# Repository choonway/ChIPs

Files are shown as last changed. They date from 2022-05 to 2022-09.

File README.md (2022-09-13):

# ChIPs - Polycube/Voxel Construction Set

## [GPGT] No more SNOT. You will only need 4 types of bricks

| polycube/voxel | ChIPs |
| --- | --- |
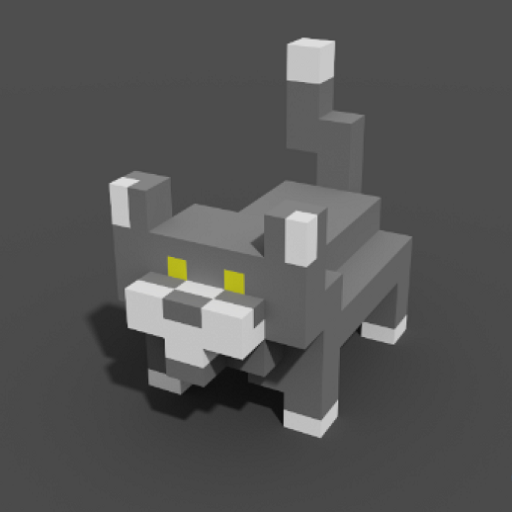
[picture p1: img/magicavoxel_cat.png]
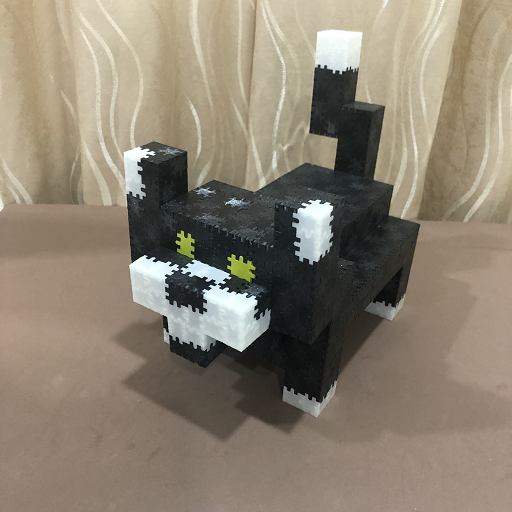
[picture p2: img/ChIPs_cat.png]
|  |  |

## tl;dr
Have you wanted to use a construction set to build a model, but don't want to deal with complicated techniques to remove studs / build sideways? Not Square? Too many different types of bricks? Something you can freely 3D print cheaply? etc. Look no further, this is the construction set for you!

## Introduction
ChIPs (Choonway's Interlocking Panels) is an open source (CC-BY 4.0) construction set system that uses interlocking finger joints between panels orientated at 0 degrees or 90 degrees with respect to each other. The resulting object has smooth surfaces on all faces, sharp edges and results in a close physical manifestation of polycube puzzles / voxel art.

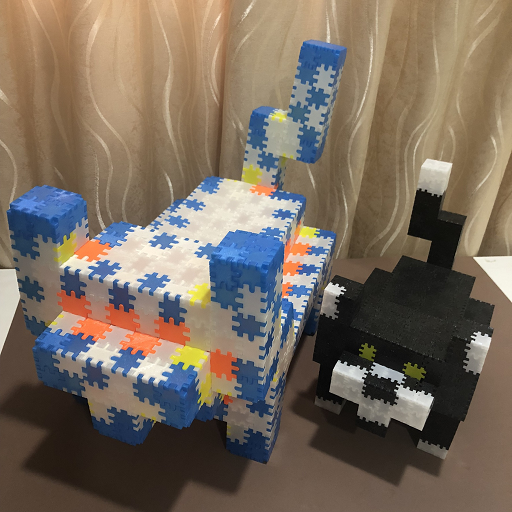
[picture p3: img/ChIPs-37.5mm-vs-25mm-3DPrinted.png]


On the left is the 37.5mm cube variant with panels colored by type. On the right is the featured cat model using 25mm cube variant with sharp corners. The dimension of the cube variant refers to the length of the side of the unit cube.

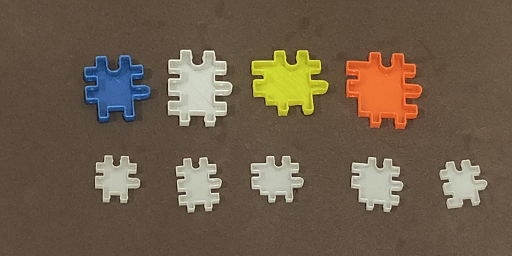
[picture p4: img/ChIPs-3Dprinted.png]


Only 4 unique panels (Blue, White, Yellow and Orange) are required for building any model. The 5th panel is optional for sharp corners. Note the sharpness of the ears between the 2 models.

## Guided Build Tutorial

At first glance it might seem confusing which panels to join together to make the object, but not to worry, there is an easy way to figure it with the use of [Ephtracy's MagicaVoxel](https://ephtracy.github.io/).

I call this the 'bubblebath' technique. vox files available [here](vox/cat_tut.vox)

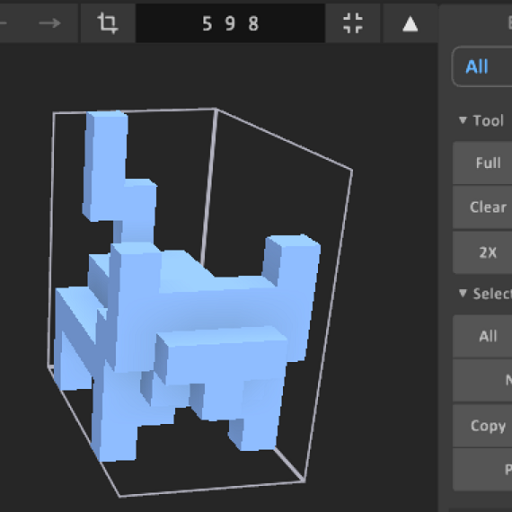
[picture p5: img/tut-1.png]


Here we start off with a cat voxel shape, with one voxel per unit cube.
Click on 'Fit Model Size' and take note of the bounding box size X = (5, 9, 8) of the original model

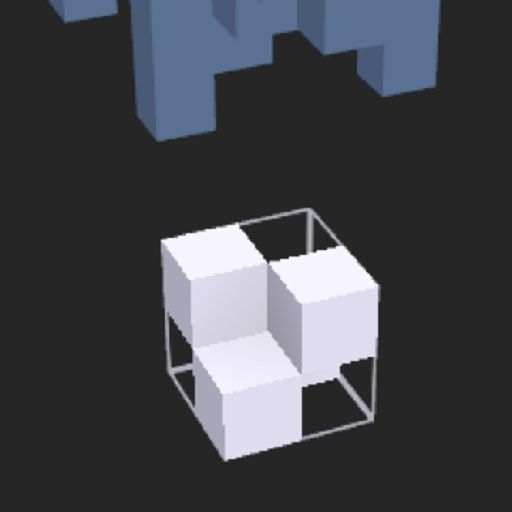
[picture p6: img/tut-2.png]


Create the unit bubble (3D checkerboard on a 2x2x2 volume)

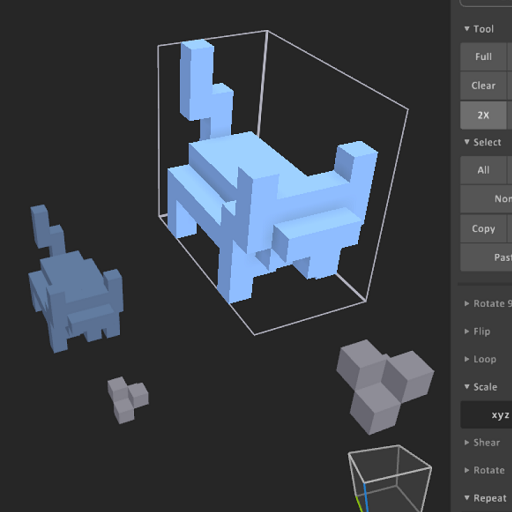
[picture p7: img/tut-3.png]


Double the size of the bubble and cat

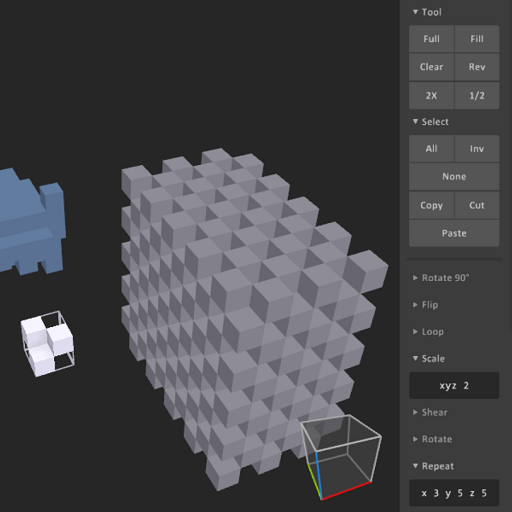
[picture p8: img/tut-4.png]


Expand the bubble using the formula below

floor(X/2)+1 = (3, 5, 5)

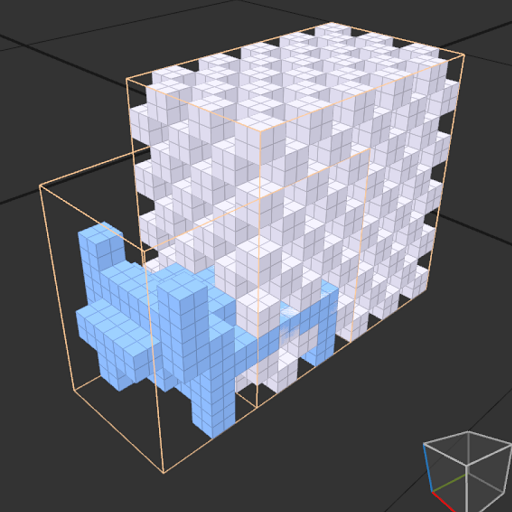
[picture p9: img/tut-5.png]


Grid lines shown for clarity.
Move the cat into the bubble, align with right face,

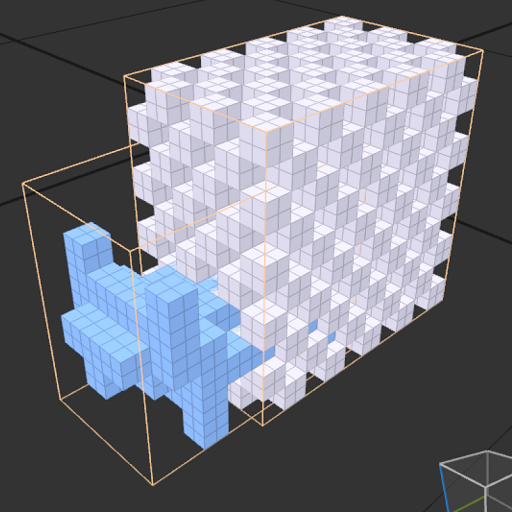
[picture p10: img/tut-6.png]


and take one step into the bubble.

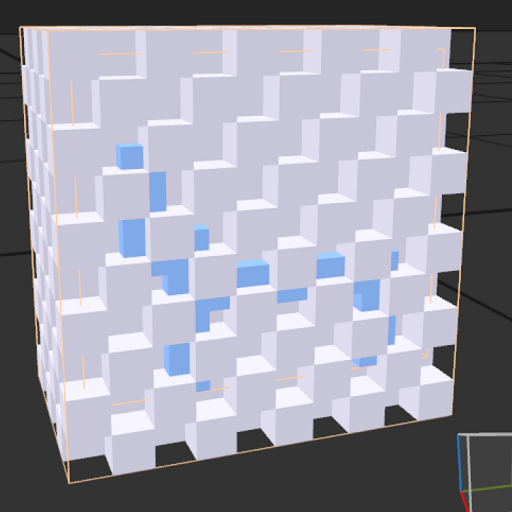
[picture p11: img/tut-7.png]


Repeat for front and top faces
In effect we are intermeshing the bubbles a half cube step with the cat model.

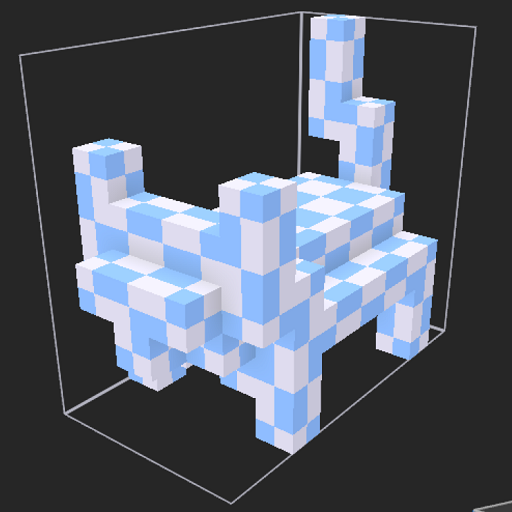
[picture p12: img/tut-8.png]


In the World View,
Click on the bubbles, then the boolean 'operand', the bubbles should disappear.
Click on the cat model, then click on the boolean 'replace', a pattern should appear on the cat.

Examine the patterns on the frazzled cat. They should match one of the 12 fragments. vox files available [here](vox/cat_frag.vox)

| fragment | ChIPs build youtube video | example locations on cat |
| --- | --- | --- |
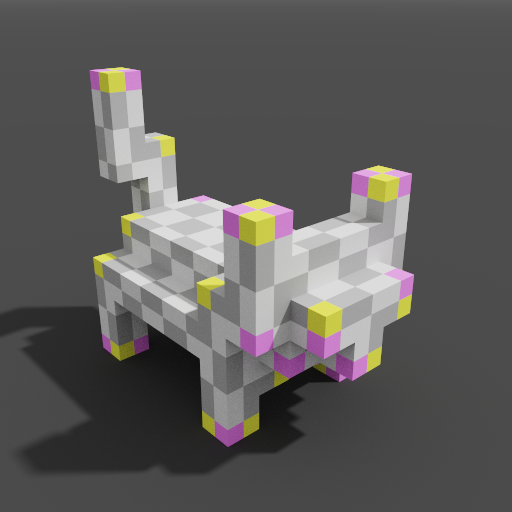
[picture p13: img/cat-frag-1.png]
| 1 | [0:04](https://www.youtube.com/watch?v=te_LA7-NAmI&t=4s) |  |
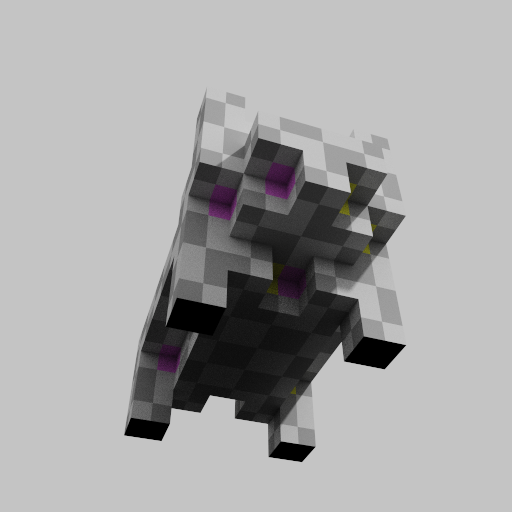
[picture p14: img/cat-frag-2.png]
| 2 | [0:22](https://www.youtube.com/watch?v=te_LA7-NAmI&t=22s) |  |
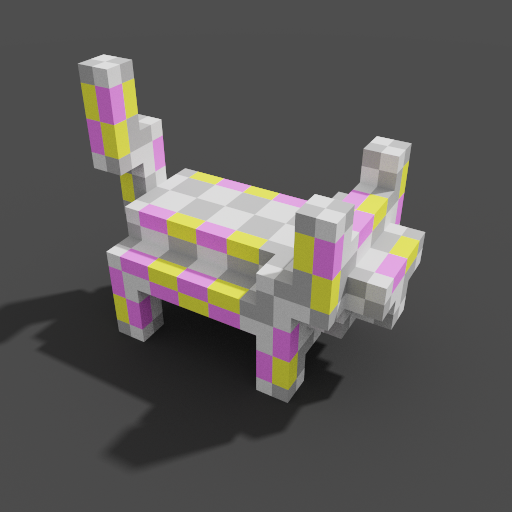
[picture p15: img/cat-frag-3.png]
| 3 | [0:44](https://www.youtube.com/watch?v=te_LA7-NAmI&t=44s) |  |
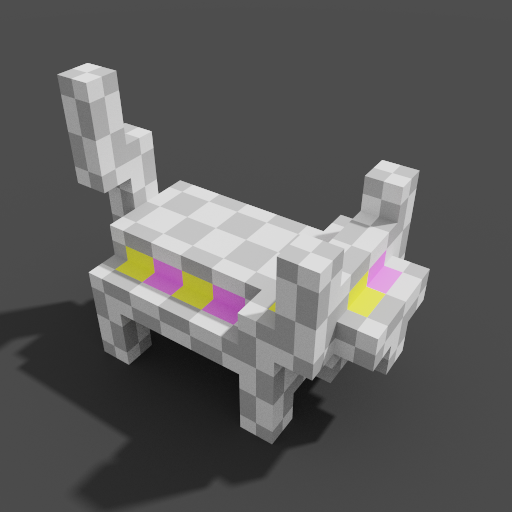
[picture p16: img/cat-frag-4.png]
| 4 | [1:14](https://www.youtube.com/watch?v=te_LA7-NAmI&t=74s) |  |
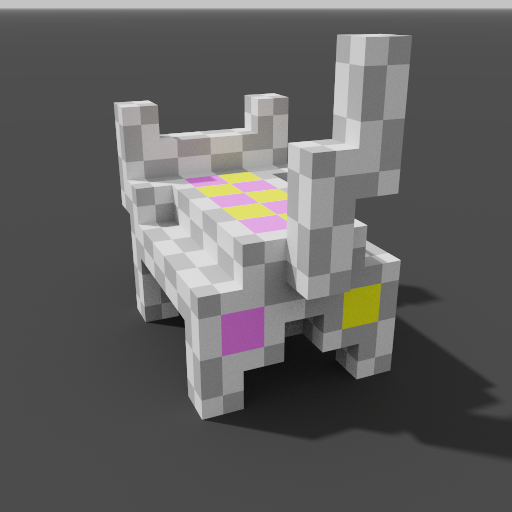
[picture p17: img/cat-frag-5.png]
| 5 | [1:54](https://www.youtube.com/watch?v=te_LA7-NAmI&t=114s) |  |
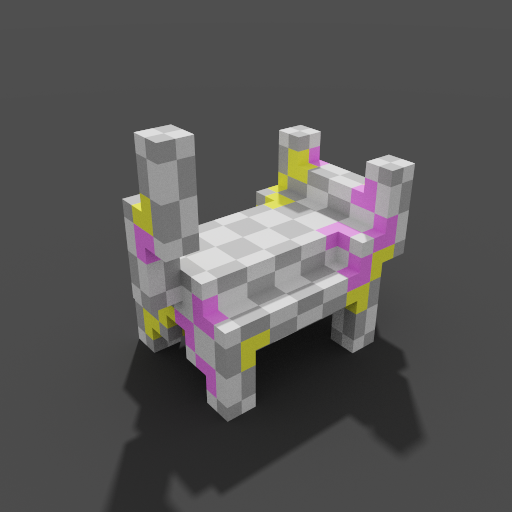
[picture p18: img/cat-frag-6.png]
| 6 | [2:25](https://www.youtube.com/watch?v=te_LA7-NAmI&t=145s) |  |
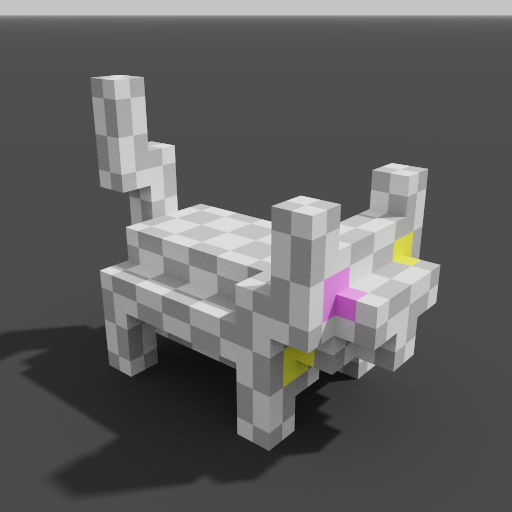
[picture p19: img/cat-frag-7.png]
| 7 | [2:56](https://www.youtube.com/watch?v=te_LA7-NAmI&t=176s) |  |
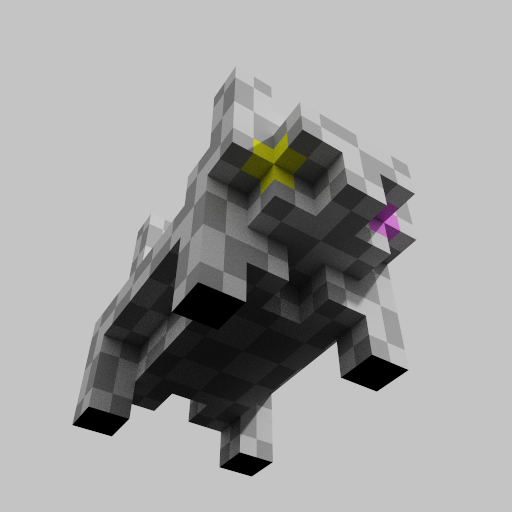
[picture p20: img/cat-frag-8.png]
| 8 | [3:31](https://www.youtube.com/watch?v=te_LA7-NAmI&t=211s) |  |
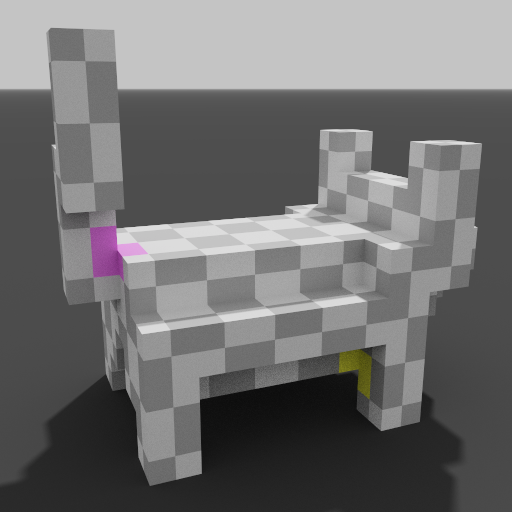
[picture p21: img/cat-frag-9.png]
| 9 | [4:29](https://www.youtube.com/watch?v=te_LA7-NAmI&t=269s) |  |
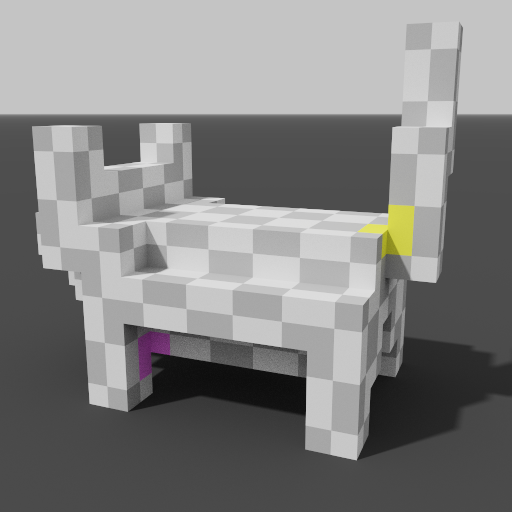
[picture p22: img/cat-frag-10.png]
| 10 | [5:14](https://www.youtube.com/watch?v=te_LA7-NAmI&t=314s) |  |
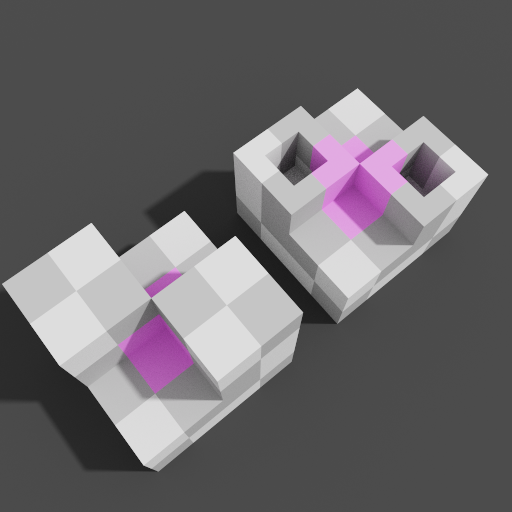
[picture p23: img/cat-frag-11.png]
| 11 | [6:00](https://www.youtube.com/watch?v=te_LA7-NAmI&t=360s) |  |
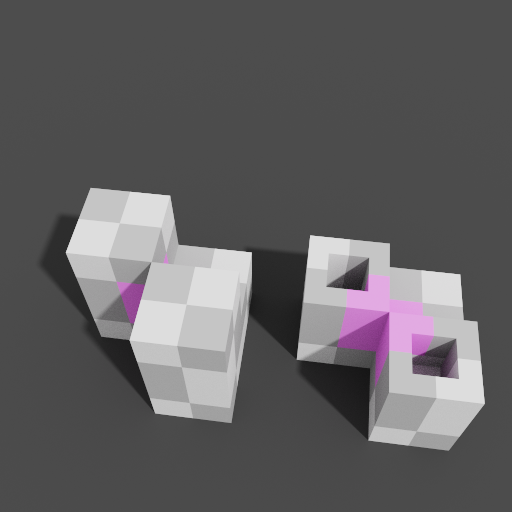
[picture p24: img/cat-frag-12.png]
| 12 | [6:53](https://www.youtube.com/watch?v=te_LA7-NAmI&t=413s) |  |

Fragments 11 and 12 are not used by the cat model. They can be tricky to identify especially if visibility on the opposite diagonal end is limited and be mistaken for Fragments 2 or 4.

Join all the fragments together and you have your cat.

It is possible, with enough practice, to build some intuition about the fragment/panels required that you can do all of this without external aids.

## Tiny Table build video

A full build of a tiny table on youtube. Click on the image below to follow the link onto youtube.

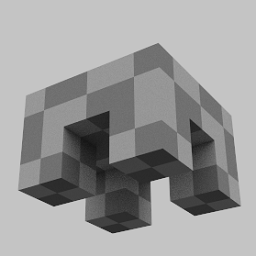
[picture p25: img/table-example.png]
(https://www.youtube.com/watch?v=VmErPDY7BgU)


vox files available [here](vox/table.vox)

## Other Examples

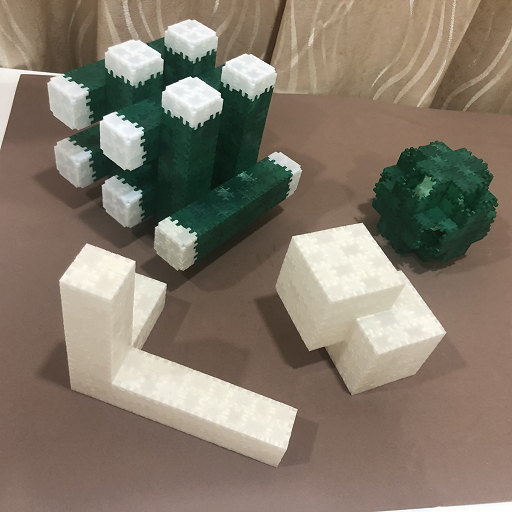
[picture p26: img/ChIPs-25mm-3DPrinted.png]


An assortment of shapes using 25mm cube variant.

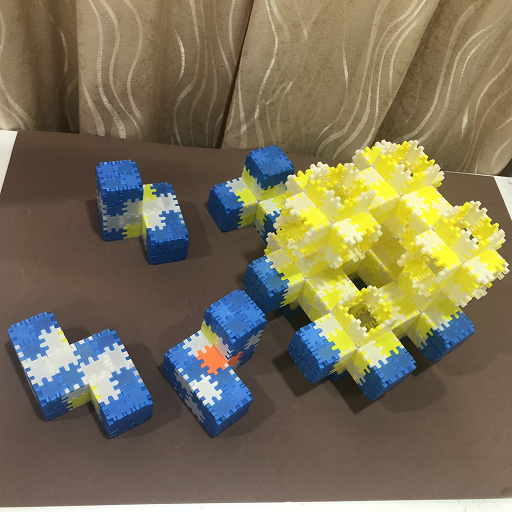
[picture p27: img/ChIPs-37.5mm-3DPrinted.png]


An assortment of shapes using 37.5mm basic cube variant.

## Manufacturing

STL files are available for both 37.5mm and 25mm basic cube variants.

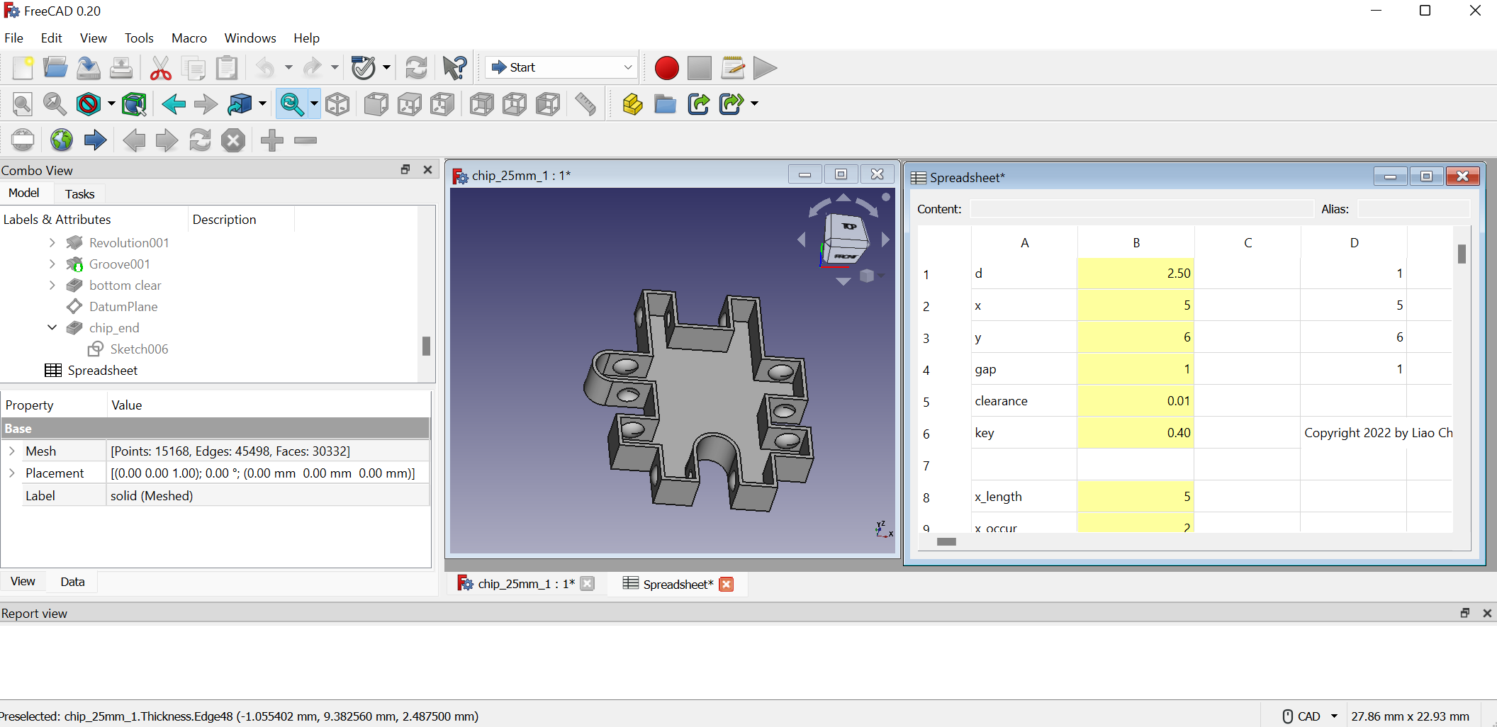
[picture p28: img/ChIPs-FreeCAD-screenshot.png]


If you want to build your own variant, parametric FreeCAD files are available. Look through the spreadsheet to adjust parameters.

The panels were designed to be printed in Vase mode, and printed in an array where each panel is printed completely before moving on to the next. The .3mf file to do this was done using PrusaSlicer.

The generated .gcode files are meant for PrusaMini+ printing using PLA. If you want to change materials you will have to go back to edit the .3mf file

Click on this [link](https://www.youtube.com/watch?v=LtgmES9rL5E) to see the print process of the 37.5mm variant panel 4. Note that this printing was done extremely conservatively - you can speed things up by editing the .3mf file

On the other hand the precompiled .gcode for the 25mm variant is done at full speed. If you have problems you can dial back the speed, or look at different brands/colors of filaments.

[Harvesting](https://www.youtube.com/watch?v=6bc6--hOfok) the panels.

## Resources

https://www.youtube.com/channel/UC7Iy1mVaFCpzOD8v4n6sJXQ

Copyright 2022 by Liao Choon Way

License: CC BY 4.0

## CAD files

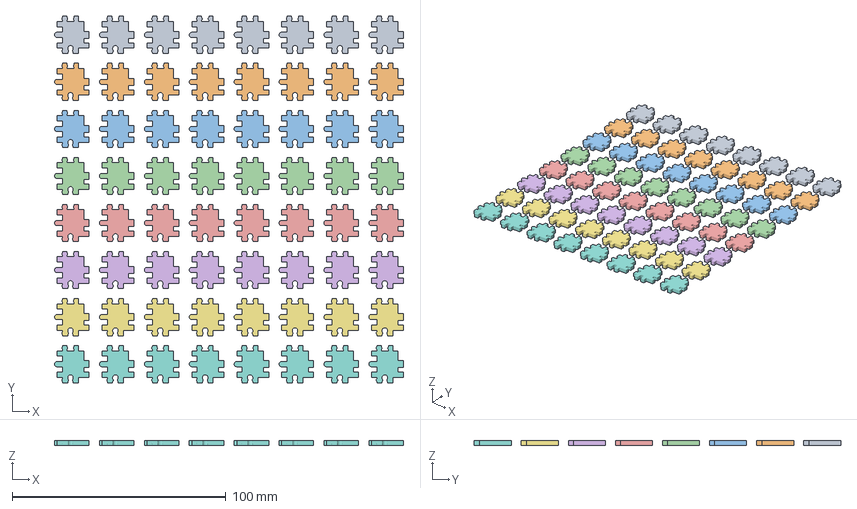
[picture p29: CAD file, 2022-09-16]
ChIPs_25/chip_25mm_4x64.3mf
163.2 x 171.5 x 2.47 mm

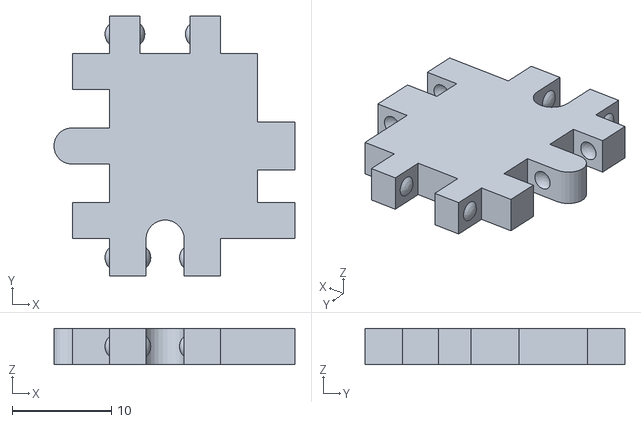
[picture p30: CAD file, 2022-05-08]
ChIPs_37.5/ChIPs_4.stl
24.3 x 26.2 x 3.65

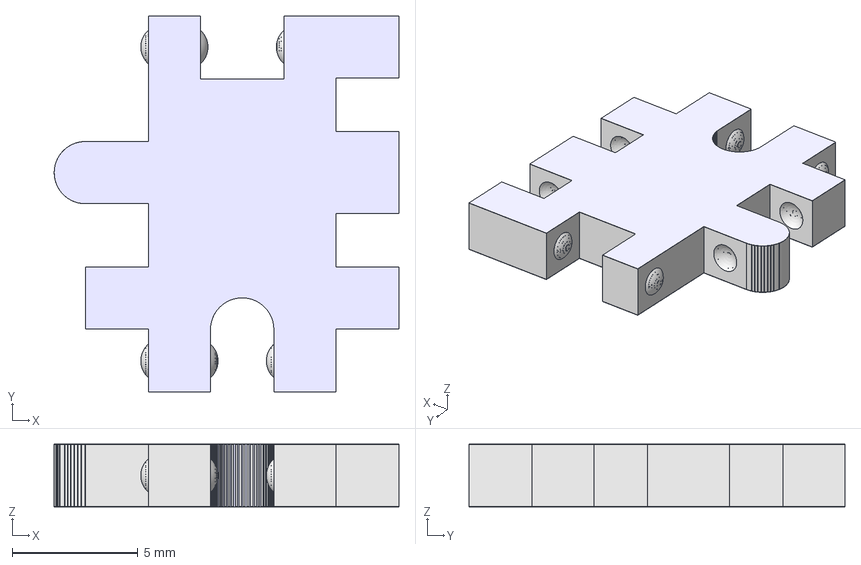
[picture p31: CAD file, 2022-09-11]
ChIPs_FreeCAD/chip_25mm_5.FCStd
13.7 x 15.0 x 2.50 mm
solid (Meshed)

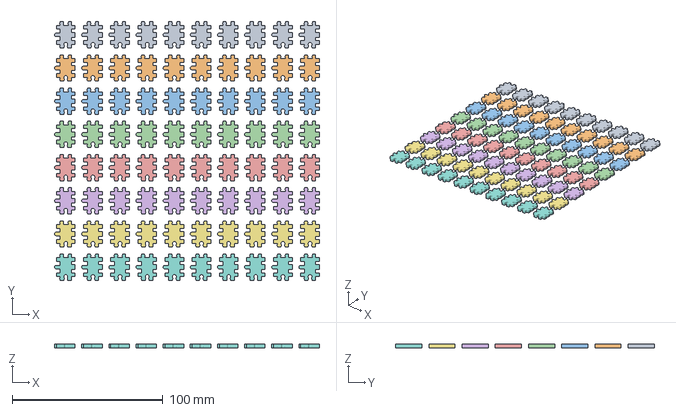
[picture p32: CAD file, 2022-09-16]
ChIPs_25/chip_25mm_2x80.3mf
175.7 x 171.5 x 2.47 mm

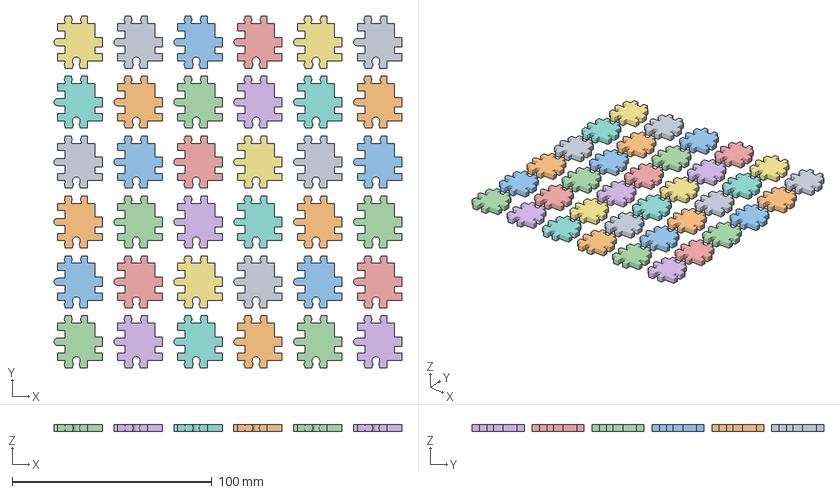
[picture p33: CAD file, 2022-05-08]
ChIPs_37.5/ChIPs_4x36.3mf
174.3 x 176.2 x 3.65 mm

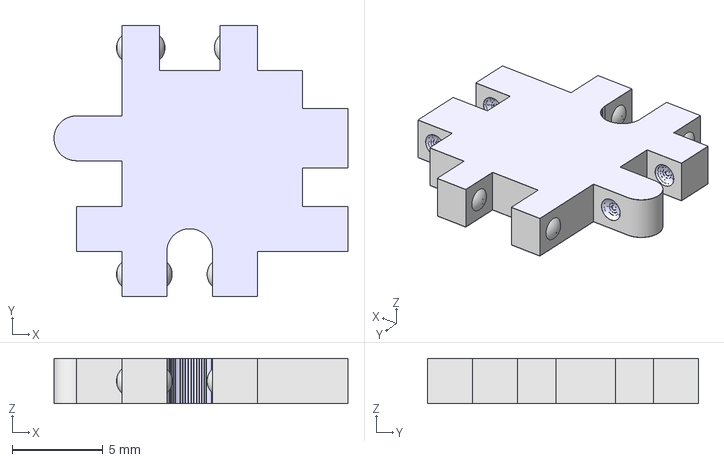
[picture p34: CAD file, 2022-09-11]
ChIPs_FreeCAD/chip_25mm_3.FCStd
16.2 x 15.0 x 2.50 mm
solid (Meshed)

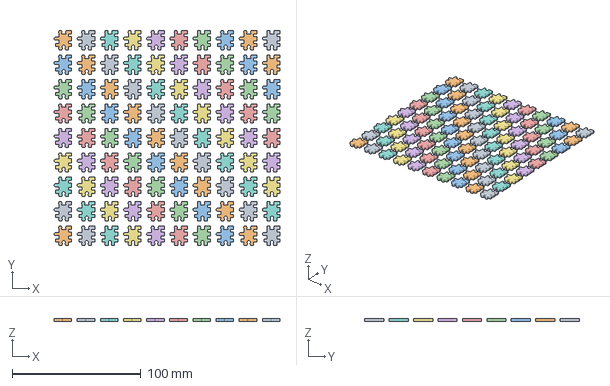
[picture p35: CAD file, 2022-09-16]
ChIPs_25/chip_25mm_5x90.3mf
175.7 x 167.0 x 2.47 mm

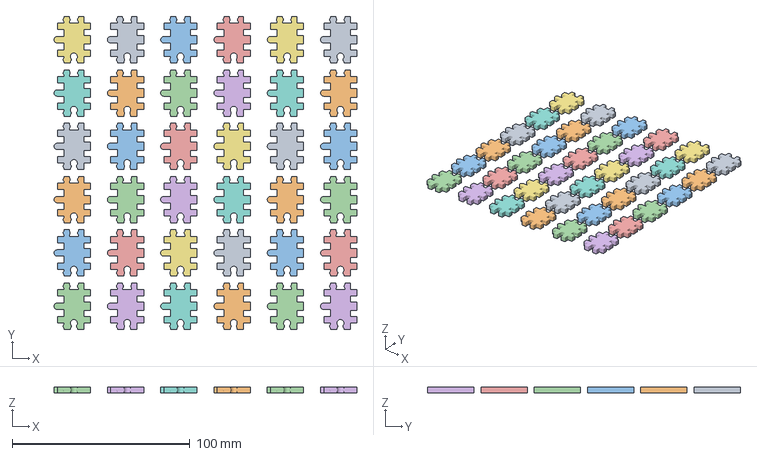
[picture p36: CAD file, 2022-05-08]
ChIPs_37.5/ChIPs_2x36.3mf
170.5 x 176.2 x 3.65 mm

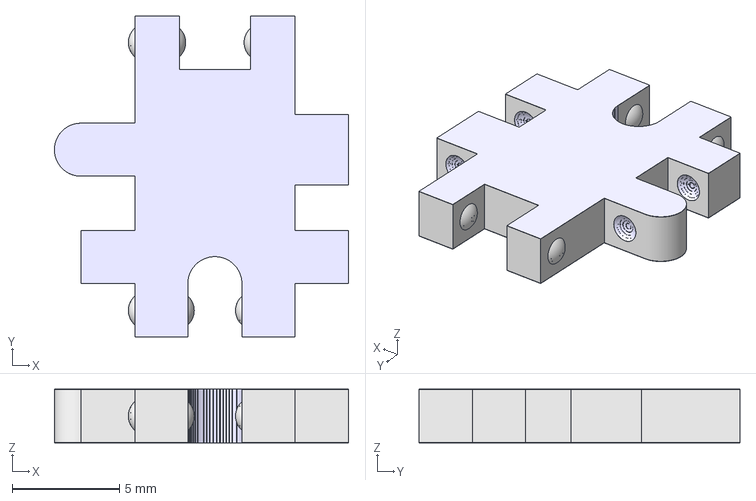
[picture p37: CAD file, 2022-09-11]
ChIPs_FreeCAD/chip_25mm_1.FCStd
13.7 x 15.0 x 2.50 mm
solid (Meshed)

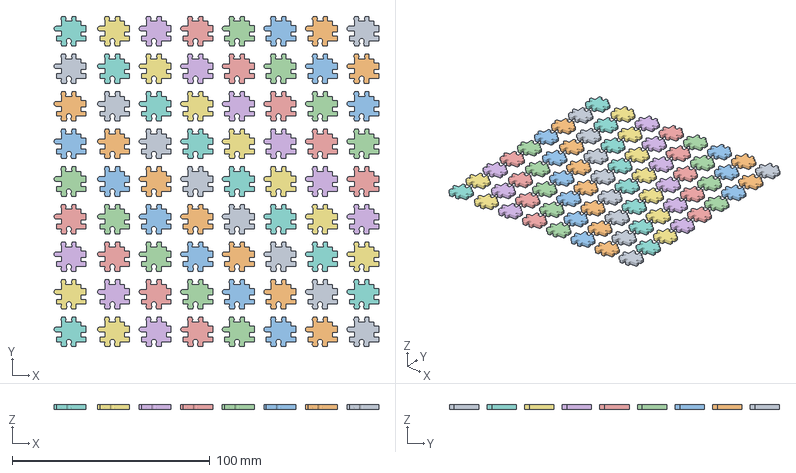
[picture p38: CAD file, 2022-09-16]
ChIPs_25/chip_25mm_3x72.3mf
164.2 x 167.0 x 2.47 mm

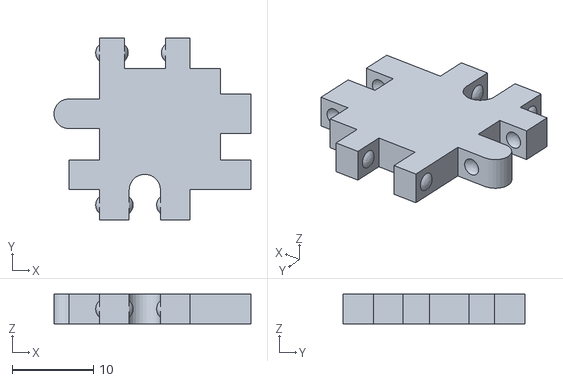
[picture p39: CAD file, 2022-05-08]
ChIPs_37.5/ChIPs_3.stl
24.3 x 22.4 x 3.65

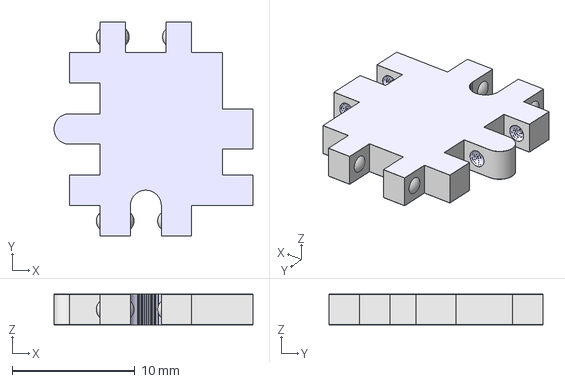
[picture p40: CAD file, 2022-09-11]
ChIPs_FreeCAD/chip_25mm_4.FCStd
16.2 x 17.5 x 2.50 mm
solid (Meshed)

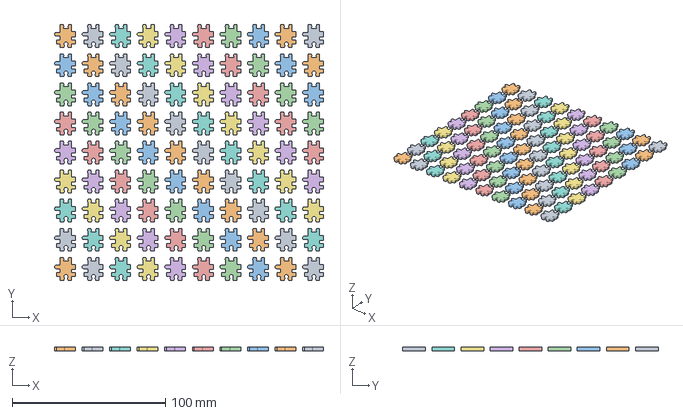
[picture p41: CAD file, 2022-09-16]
ChIPs_25/chip_25mm_1x90.3mf
175.7 x 167.0 x 2.47 mm

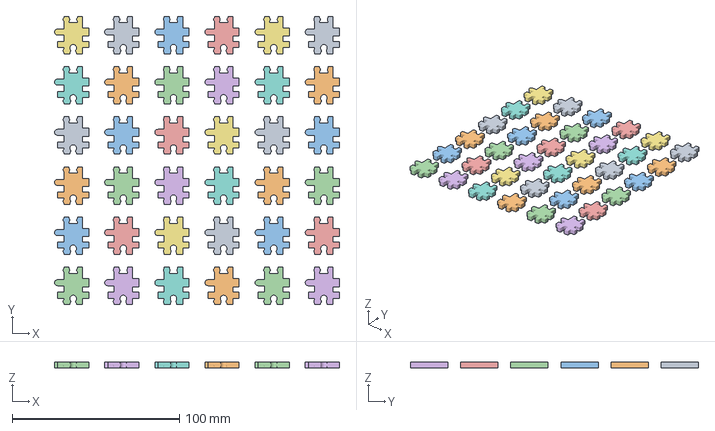
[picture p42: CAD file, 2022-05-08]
ChIPs_37.5/ChIPs_1x36.3mf
170.5 x 172.4 x 3.65 mm

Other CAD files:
ChIPs_FreeCAD/chip_25mm_2.FCStd
ChIPs_25/chip_25mm_5.stl
ChIPs_37.5/ChIPs_3x36.3mf
ChIPs_25/chip_25mm_1.stl
ChIPs_25/chip_25mm_2.stl
ChIPs_25/chip_25mm_3.stl
ChIPs_25/chip_25mm_4.stl
ChIPs_37.5/ChIPs_1.stl
ChIPs_37.5/ChIPs_2.stl

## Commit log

2022-09-11 cleaned up, added 25mm, added freecad, added images
    old files moved to 37.5 folder
    added 25 variant
    added freecad sources
    added images
    [ChIPs_1.stl, ChIPs_1x36.3mf, ChIPs_2.stl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]
2022-09-16 updated with spiral print for top layer
    updated with spiral print for top layer
    new feature with prusaslicer 2.50
    improve adhesion at start of spiral
    [chip_25mm_1.3mf, chip_25mm_1x90.3mf, chip_25mm_2.3mf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]
2022-09-16 treat *.gcode as binary
    treat *.gcode as binary or else printer will be confused.
